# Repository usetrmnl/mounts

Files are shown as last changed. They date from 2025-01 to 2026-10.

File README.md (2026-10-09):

# TRMNL Mounts

this repo contains a growing collection of 3D printable models, useful for attaching TRMNL to magnetic surfaces like refrigerators or non stationary locations like a moving door.

to kickstart your own design, check out the `/resources` directory for component and enclosure STLs.

---

Mac 128k Display

designed by [@Jerrodh](https://makerworld.com/en/models/1516432-mac-128k-display-stand-for-trmnl-e-ink-dashboard#profileId-1588587)

---

### MainFrame

<kbd>TRMNL-MainFrame-Black</kbd>

designed by [Yogesh](https://makerworld.com/en/@mhatrey), [get the files](https://makerworld.com/en/models/1565549-mainframe-for-trmnl) or [watch the live demo](https://www.youtube.com/watch?v=4wjz7EKg_lw).

---

### anti-theft / public venue wall mount (OG)

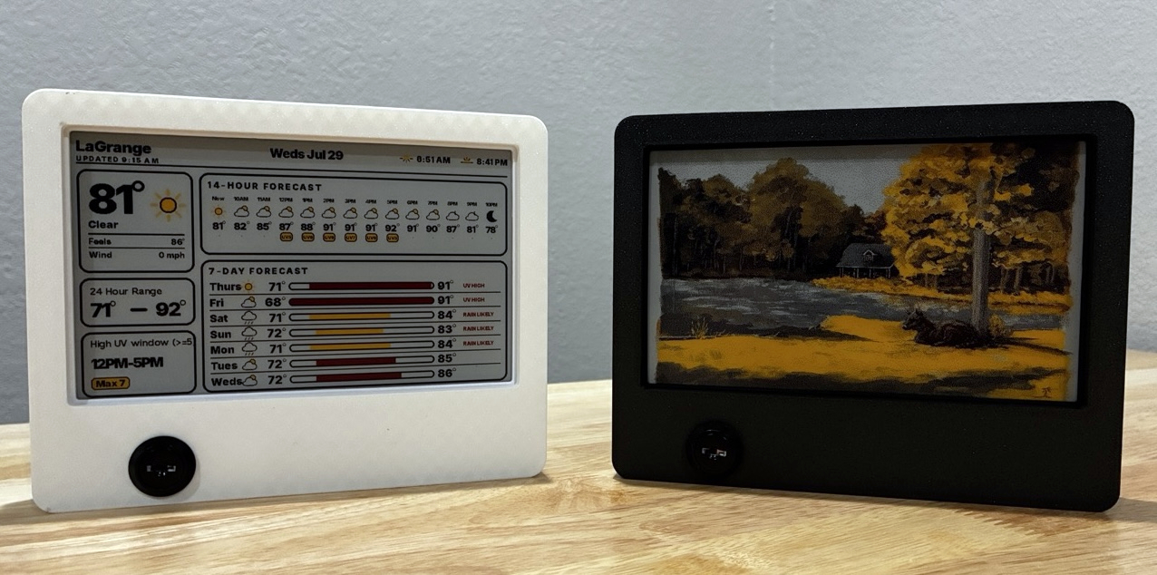
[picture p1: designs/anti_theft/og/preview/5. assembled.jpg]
anti-theft-og-preview


designed by TRMNL, [get the files](https://github.com/usetrmnl/mounts/tree/main/designs/anti_theft/og)

---

### X low profile mount

<kbd>x-low-profile-wall-mount</kbd>

designed by [@Bas](https://www.printables.com/model/1771188-trmnl-x-low-profile-mount), requires 4 (four) 10mm x 2mm magnets.

### hidden magnet

<kbd>minimal-magnet</kbd>

designed by [@jerieljan](https://x.com/jerieljan/status/1981025845100552695), **no 3D printer required**, just find/buy 30mm x 10mm x 3mm N42 NdFeB magnets.

---

### OG Faceplate Cover

<kbd>trmnl-og-faceplate-cover</kbd>

designed by [@maxelman](https://www.printables.com/model/1478341-trmnl-og-faceplate-cover)

---

### X Magnetic Fridge Mount

<kbd>trmnl-x-fridge-mount</kdb>

designed by [@t0nyz](https://makerworld.com/en/models/3391454-trmnl-x-magnetic-fridge-mount), requires 20mm x 10mm x 2 mm magnets.

---

### Multiboard TRMNL Mount

<kbd>multiboard-trmnl-mount</kdb>

designed by [@shahriar](https://makerworld.com/en/models/2436099-multiboard-trmnl-mount#profileId-2672745)

---

### Waveshare driver board

<kbd>!doctor-volt-cad</kbd>

requires [FreeCAD](https://www.freecad.org/), designed by [DoctorVolt](https://www.hackster.io/michalin70/build-your-own-ultra-low-power-e-ink-dashboard-3889ab) (file linked within).

---

### fridge magnet

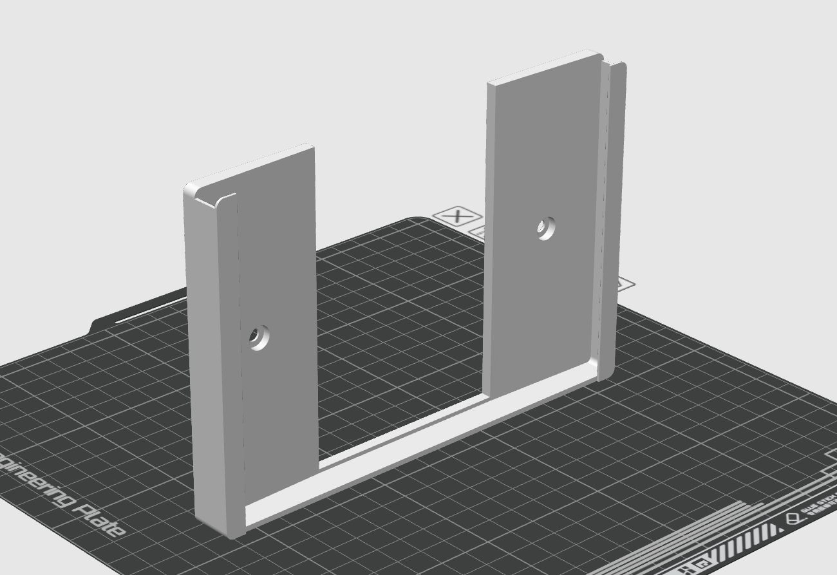
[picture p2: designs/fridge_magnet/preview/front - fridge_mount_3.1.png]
trmnl-fridge-magnet-front-preview
<kbd></kbd>

designed by TRMNL, [get the files](https://github.com/usetrmnl/mounts/tree/main/designs/fridge_magnet)

---

### OG mount for VESA arm system

<kbd>trmnl-vesa-mount</kbd>

requires VESA plate, designed by [az3dr](https://www.thingiverse.com/thing:7304914).

---

### sturdy fridge magnet

<kbd>trmnl-beefy-fridge-magnet</kbd>

designed by [@erikbuild](https://www.printables.com/model/1311911-trmnl-sturdy-fridge-magnet-mount)

---

### magnetic mounting plate

trmnl-magnetic-mounting-plate

designed by [@deisterhold](https://makerworld.com/en/models/1388620-trmnl-magnetic-mounting-plate#profileId-1438495)

---

### corner bracket

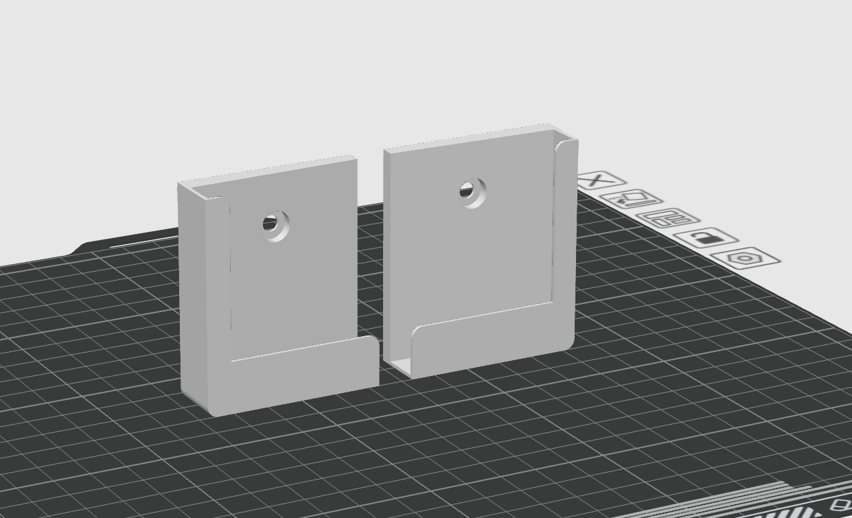
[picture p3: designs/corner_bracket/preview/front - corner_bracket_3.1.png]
corner-bracket-front-preview


designed by TRMNL, [get the files](https://github.com/usetrmnl/mounts/tree/main/designs/corner_bracket)

---

### Minimal Stand

trmnl-stand-ctrl-alt

designed by [@CtrlAlt](https://makerworld.com/en/models/1267576-trmnl-stand-for-e-ink-dashboard)

---

### BRKT

trmnl-brkt-jonschwenn

designed by [@jonschwenn](https://www.printables.com/model/1194757-trmnl-brkt)

---

### TRMNL Stand

trmnl-stand-rafbanaan

designed by [@rafbanaan](https://makerworld.com/en/models/1094514)

---

### TRMNL Command Strip

trmnl-command-strip-nail-hanger

designed by [@jgcaruso](https://makerworld.com/en/models/1189641-trmnl-command-strip-nail)

---

### [WIP] The H

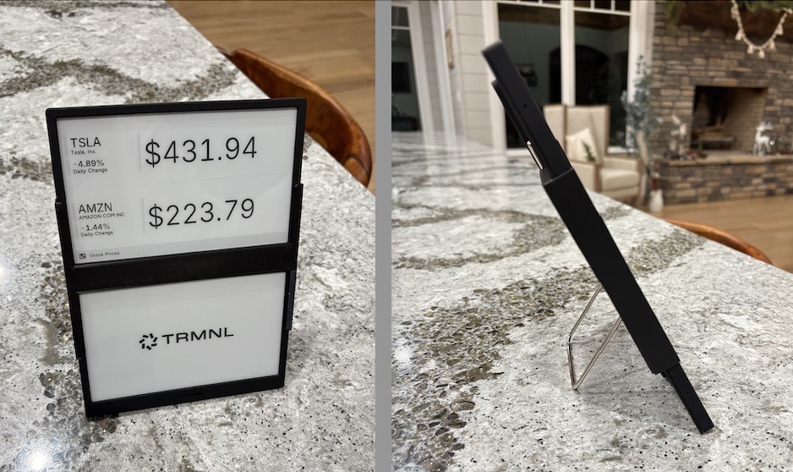
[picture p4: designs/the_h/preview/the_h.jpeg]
the-h-wip-preview


---

### SKÅDIS mount #1

trmnl-skadis

designed by [@coops on MakerWorld](https://makerworld.com/en/models/1156997-trmnl-skadis-mount)

---

### SKÅDIS mount #2

trmnl-skadis-2

designed by [@trakais on MakerWorld](https://makerworld.com/en/models/1469457-tmrnl-mini-hook-for-ikea-skadis-pegboard#profileId-1533577)

---

### Faceplate Cover

TRMNL-faceplate-cover

designed by [@Apolluna](https://www.printables.com/model/1313342-trmnl-faceplate-cover)

---

### TRMNL OG DIY Kit 10" Rack Mount

TRMNL-OG-DIY-Kit-10-Rack-Mount

designed by [@Lollo](https://www.printables.com/model/1575922-trmnl-og-diy-kit-10-rack-mount)

---

### Minimalist Mount for 19" Rack Blank Plate

TRMNL server rack mount

designed by [@erikbuild](https://www.printables.com/model/1316341-trmnl-minimalist-mount-for-19-rack-blank-plate)

---

### Wall Mount with button access and magnet+adhesive support

TRMNL button friendly wall mount

designed by [@curby](https://www.printables.com/model/1316584-trmnl-button-mount)

---

### Magnetic backplate

TRMNL-magnetic-backplate

designed by [@jareware_2647066](https://www.printables.com/model/1316234-trmnl-magnetic-backplate)

---

### Yet Another Magnetic TRMNL Mount

Magnetic TRMNL Mount

designed by [@sethangell](https://makerworld.com/en/models/1513288-magnetic-trmnl-mount#profileId-1584851)

---

### TRMNL BMP280

trmnl-bmp280-mount

designed by [@lanrat](https://github.com/lanrat/trmnl_plugins/blob/main/3D_models/Trmnl%20BMP280%20mount/README.md) for [DIY Environment Sensors](https://trmnl.com/blog/environment-sensors/)

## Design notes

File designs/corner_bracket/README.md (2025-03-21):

# TRMNL Mount - Corner Bracket

for placement on non-magnetic moving surfaces like doors, where the built-in recessed hook hole would be insufficient. also useful as a jig to arrange an array of devices on a wall with precisely butted edges.

### features

- 3x recessed spots on the back for magnet placement (5/8" diameter - ex [N35 Neodymium](https://www.magnet4sale.com/neodymium-magnet-n35-dia-5-8x1-16-disc-magnet-rare-earth-magnets/))
- 1x recessed screw hole for `#8` (Imperial) screw heads

### print instructions

DIY:

1. import STL file to any slicer tool (STEP file also provided for edits)
2. disable supports / not required
3. ~any infill should be fine

Online: we hear good things about Craft Cloud:
[https://craftcloud3d.com/upload](https://craftcloud3d.com/upload)

### installation

if using magnets, we recommend super glue with an extended curing time. your brand's bottle may require just 30-45 seconds, but in testing our magnets detached from the mount unless given at least 60 minutes to dry.

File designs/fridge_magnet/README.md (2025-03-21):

# TRMNL Mount - Fridge Magnet

for placement on magnetic surfaces, such as a kitchen fridge. may not work on smaller bar fridges or ice machines due to materials used in constructions.

### features

- easy removal from the mount for battery charging (entire mount can also be removed)
- recessed spots for up to 6x magnets (5/8" diameter - ex [N35 Neodymium](https://www.magnet4sale.com/neodymium-magnet-n35-dia-5-8x1-16-disc-magnet-rare-earth-magnets/))

in testing we found that only 3-4x magnets are required on flat surfaces. if a refrigerator door is curved, 6x magnets are recommended. if the magnetic surface is flat but some household members prefer to slam doors, 6x magnets are recommended.

### print instructions

DIY:

1. import STL file to any slicer tool (STEP file also provided for edits)
2. disable supports / not required
3. recommend 30% infill with rectilinear infill pattern

Online: we hear good things about Craft Cloud:
[https://craftcloud3d.com/upload](https://craftcloud3d.com/upload)

### installation

if using magnets, we recommend super glue with an extended curing time. your brand's bottle may require just 30-45 seconds, but in testing our magnets detached from the mount unless given at least 60 minutes to dry.

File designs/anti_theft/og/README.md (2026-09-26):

# TRMNL Mount - OG Anti-Theft (Public Venue)

anti-theft-og-preview

for public spaces with low supervision. incorporates a barrel lock and dovetail mechanism to prevent unauthorized removal.

### features

- 4x recessed screw holes on wall plate that fit most common fasteners
- works with generic 5/8" cam (barrel) locks (designed for [this model](https://www.amazon.com/dp/B0D72LGKTR))
- easy removal for ongoing charging and maintenance

### print instructions

DIY:

1. import STL file to any slicer tool (STEP file also provided for edits)
2. disable supports (not required)
3. ~any infill should be fine
4. PETG recommended but Basic PLA also works

Online: we hear good things about Craft Cloud:
[https://craftcloud3d.com/upload](https://craftcloud3d.com/upload)

### installation

see photos inside "preview" directory and follow along below:

1. attach back plate to a surface of your choice
2. put locking frame face down and insert OG device upside down (kickstand facing you)
3. slide cam lock into opposite side of locking frame, attach straight cam in vertical orientation
4. carefully attach locking frame to wall plate but aligning slots, then pushing locking frame downward
5. insert cam lock key and turn counter-clockwise to lock it against the wall plate's bottom hook

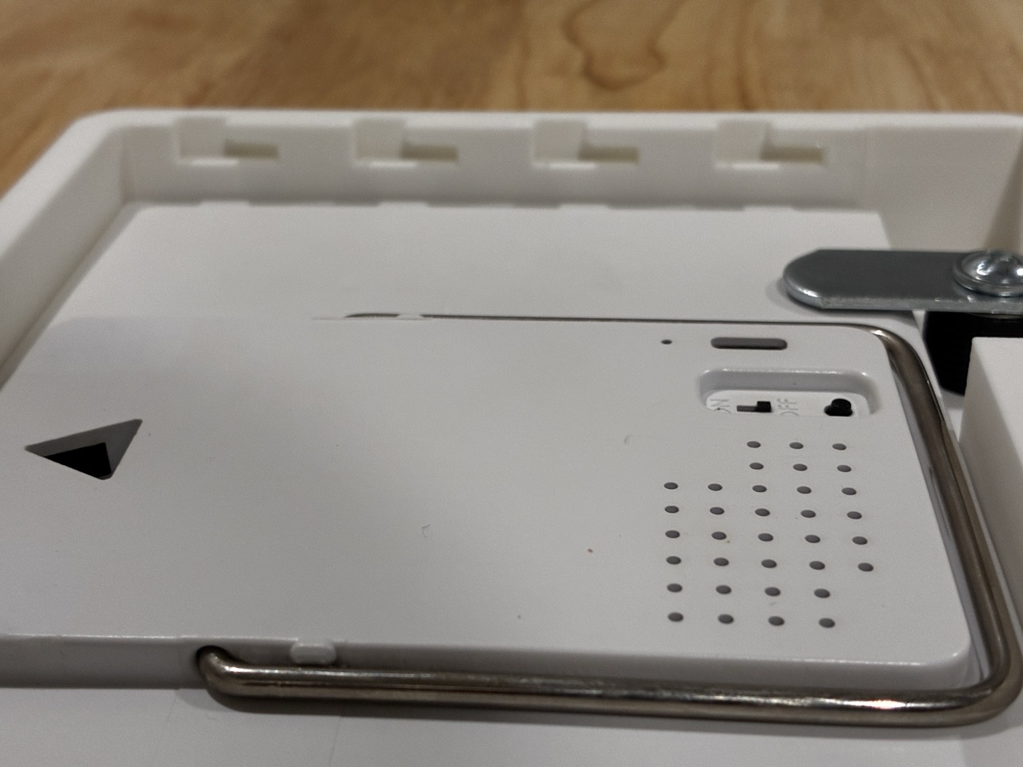
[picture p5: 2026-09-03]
designs/anti_theft/og/preview/3. wall plate slots.jpeg

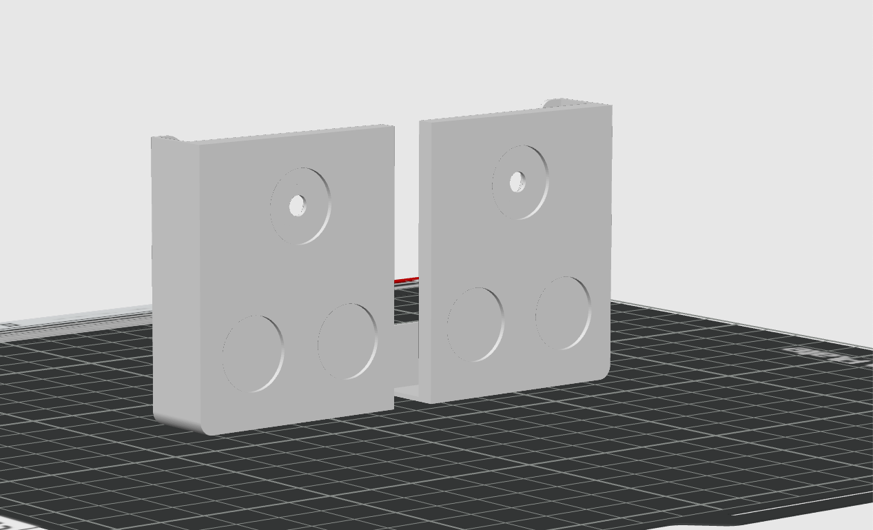
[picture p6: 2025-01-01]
designs/corner_bracket/preview/back - corner_bracket_3.1.png

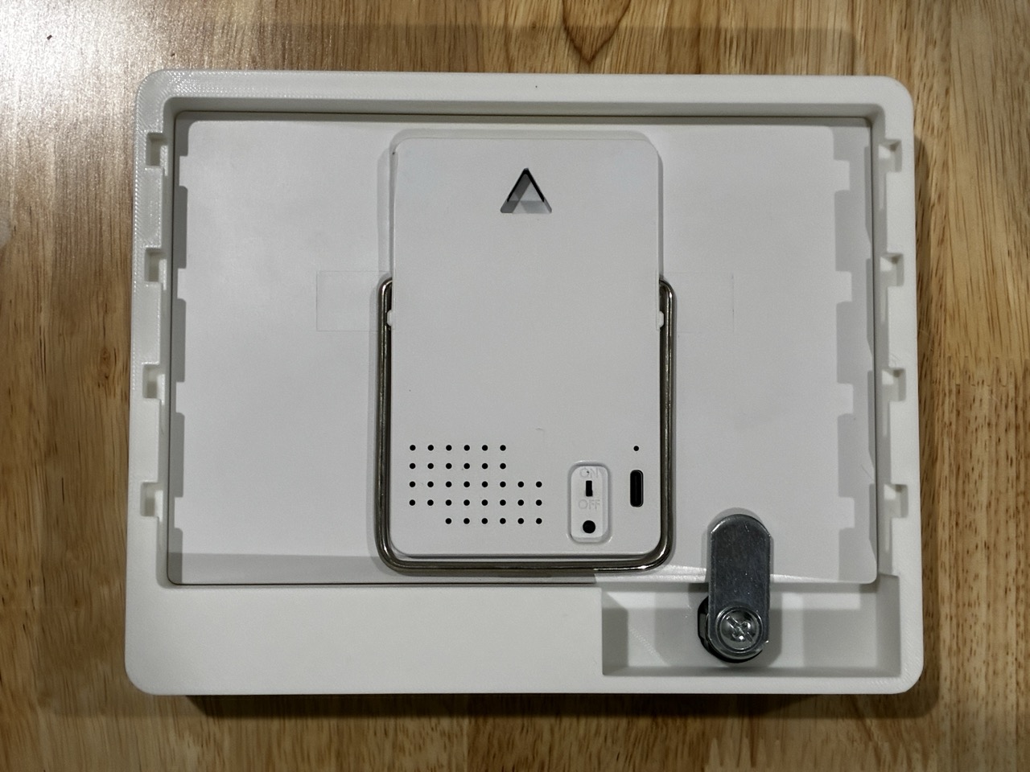
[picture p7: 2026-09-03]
designs/anti_theft/og/preview/2. device insertion.jpeg

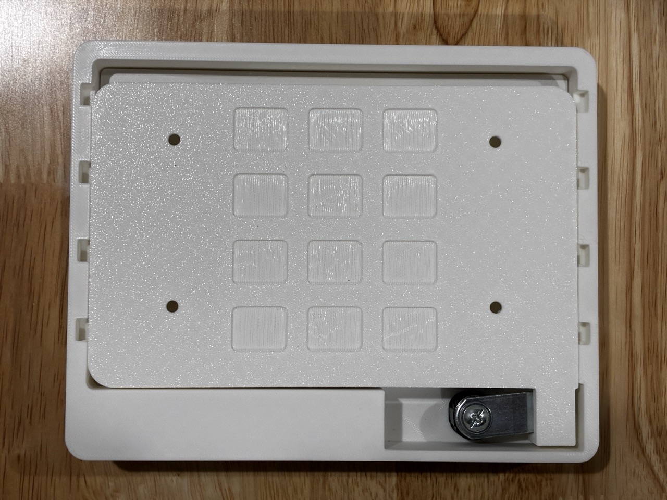
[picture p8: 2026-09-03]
designs/anti_theft/og/preview/4. cam lock.jpeg

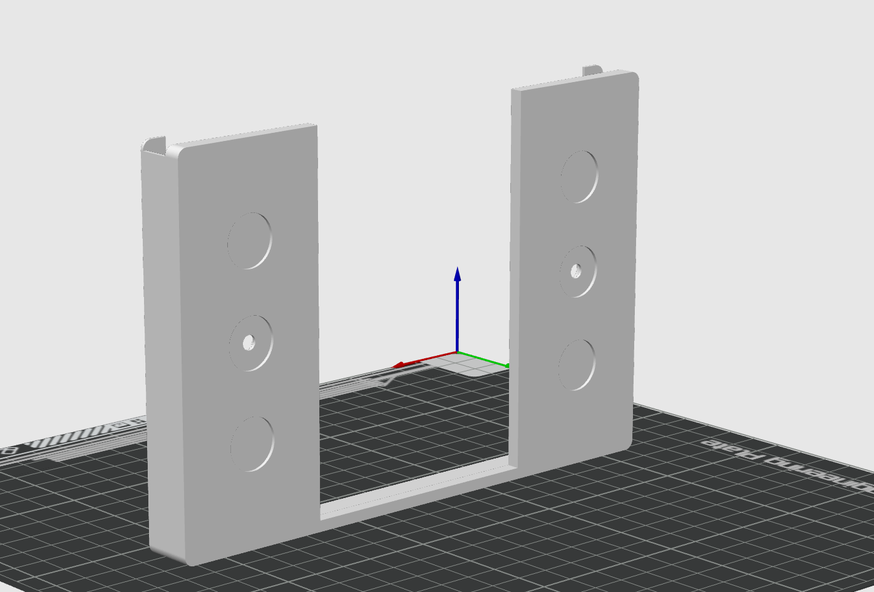
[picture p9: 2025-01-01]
designs/fridge_magnet/preview/back - fridge_mount_3.1.png

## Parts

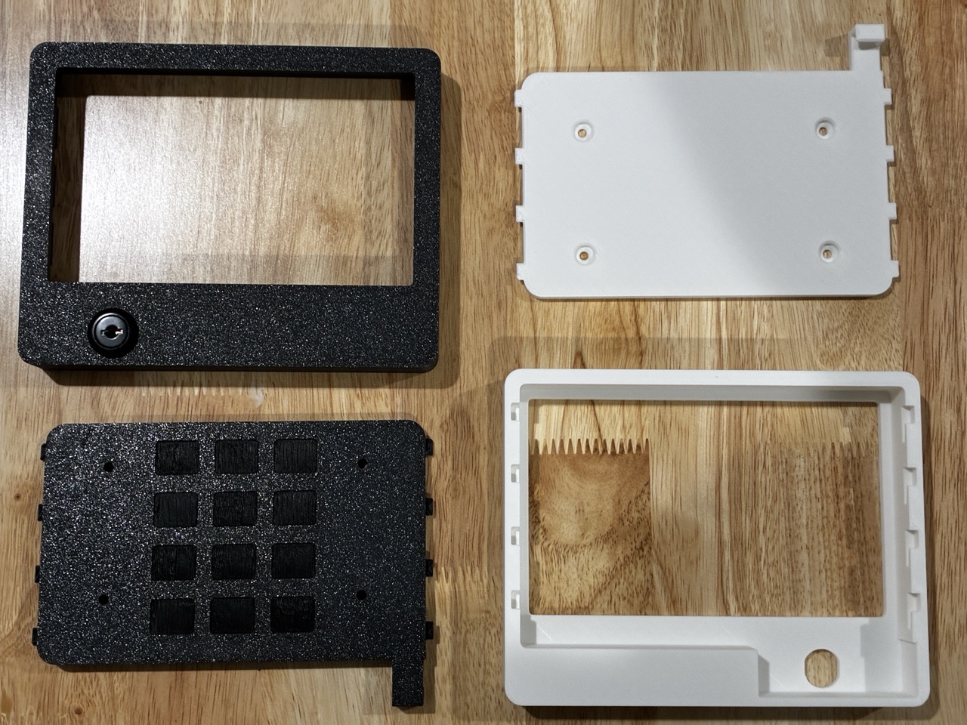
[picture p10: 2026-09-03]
designs/anti_theft/og/preview/1. individual components.jpeg

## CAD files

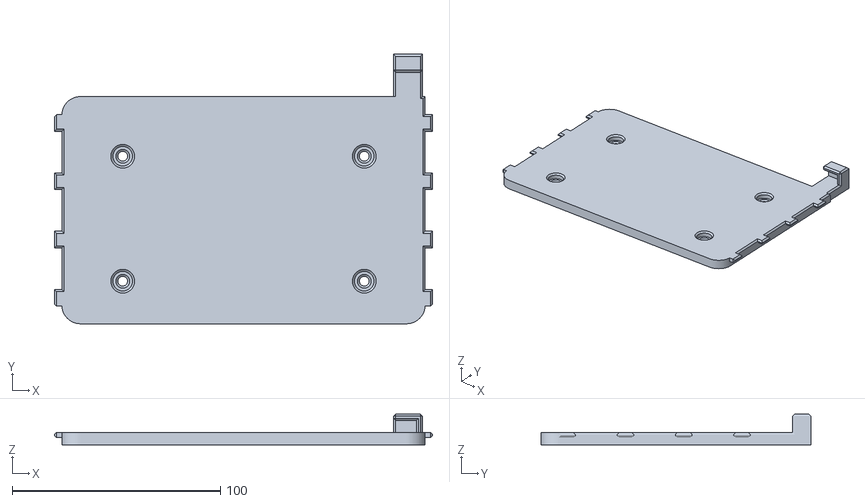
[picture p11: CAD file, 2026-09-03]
designs/anti_theft/og/wall_plate.stl
181.5 x 129.5 x 14.8

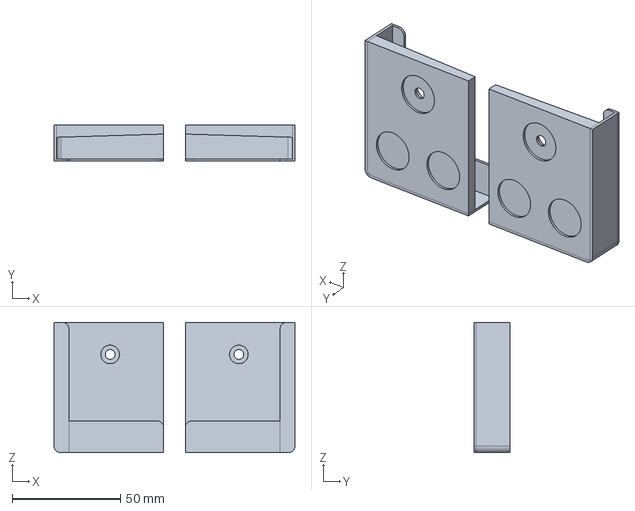
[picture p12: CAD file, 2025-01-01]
designs/corner_bracket/corner_bracket_3.1.stp
111.2 x 16.6 x 60.0 mm

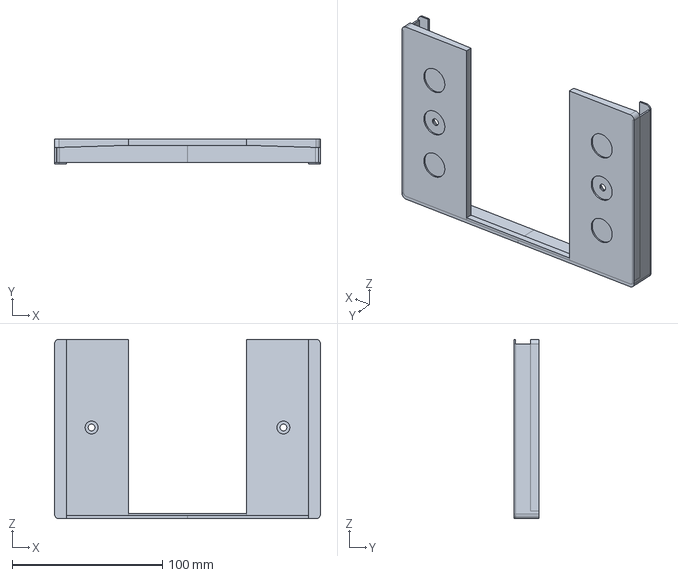
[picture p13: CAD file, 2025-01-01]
designs/fridge_magnet/fridge_mount_3.1.stp
177.2 x 16.6 x 119.5 mm

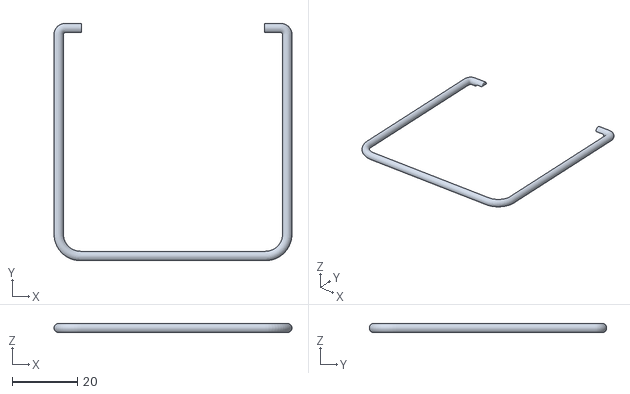
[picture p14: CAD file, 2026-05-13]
resources/og_model/KICKSTAND-2.4.stl
73.1 x 72.9 x 2.90

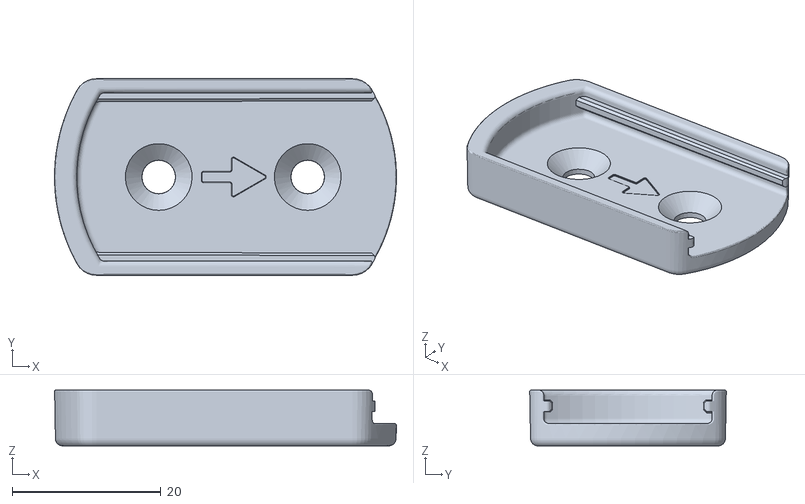
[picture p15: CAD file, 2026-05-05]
resources/x_model/U_MOUNT.stl
45.9 x 26.4 x 7.50

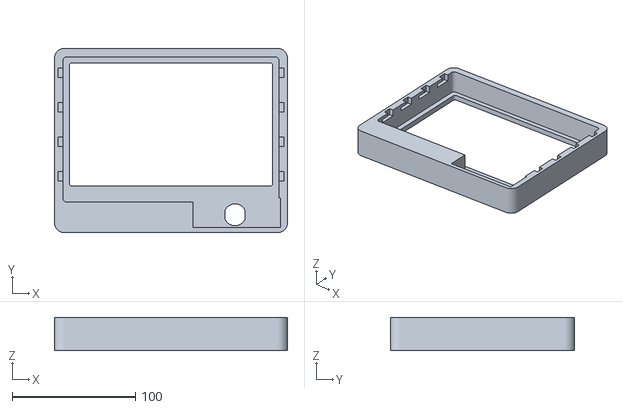
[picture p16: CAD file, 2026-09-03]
designs/anti_theft/og/locking_frame.stl
189.1 x 149.6 x 26.8

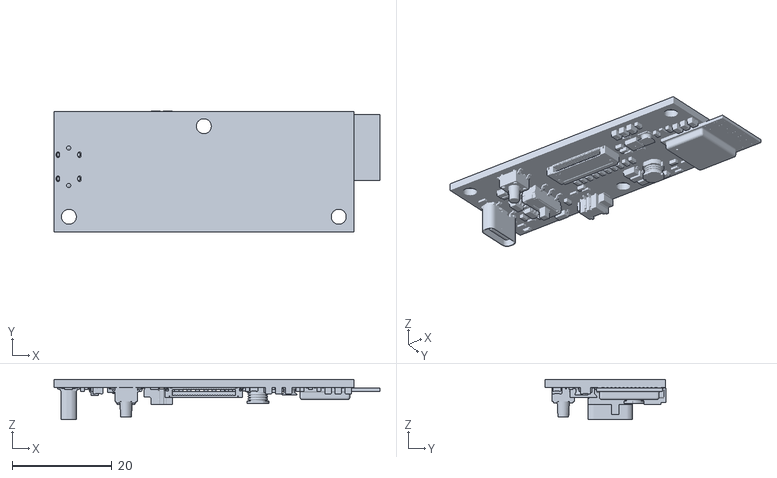
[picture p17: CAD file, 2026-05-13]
resources/og_model/PCBA.stl
65.2 x 24.2 x 8.10

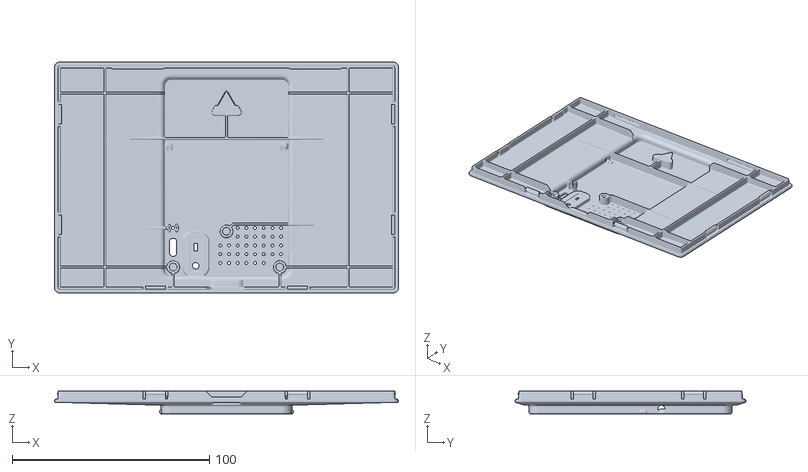
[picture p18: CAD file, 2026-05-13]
resources/og_model/ENCLOSURE_BACK-2.4.stl
174.3 x 116.9 x 11.6

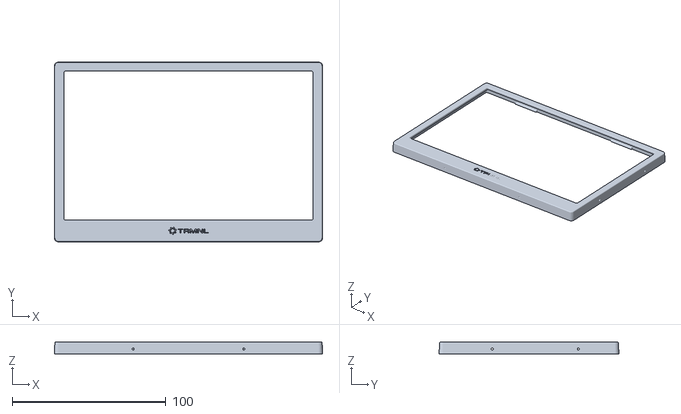
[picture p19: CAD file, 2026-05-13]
resources/og_model/ENCLOSURE_FRONT-2.4.stl
174.3 x 116.9 x 7.70

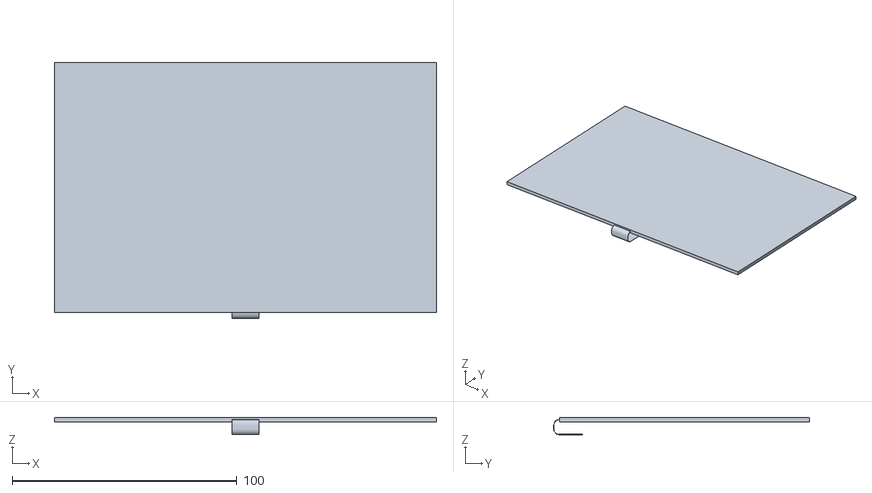
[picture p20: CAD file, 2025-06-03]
resources/og_model/EPD.stl
170.0 x 113.8 x 7.73

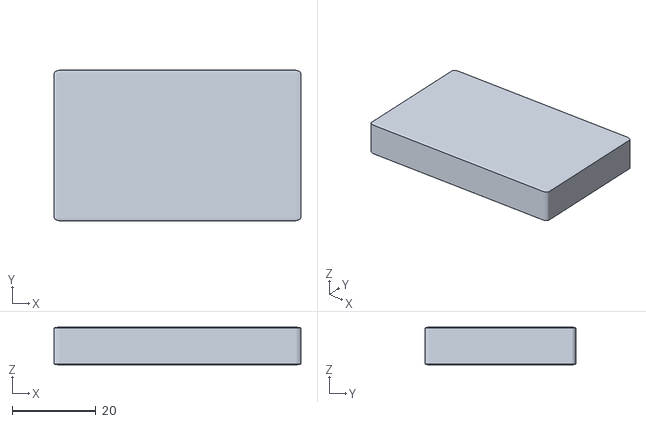
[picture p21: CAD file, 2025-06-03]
resources/og_model/BATTERY_LARGE.stl
59.0 x 36.0 x 9.00

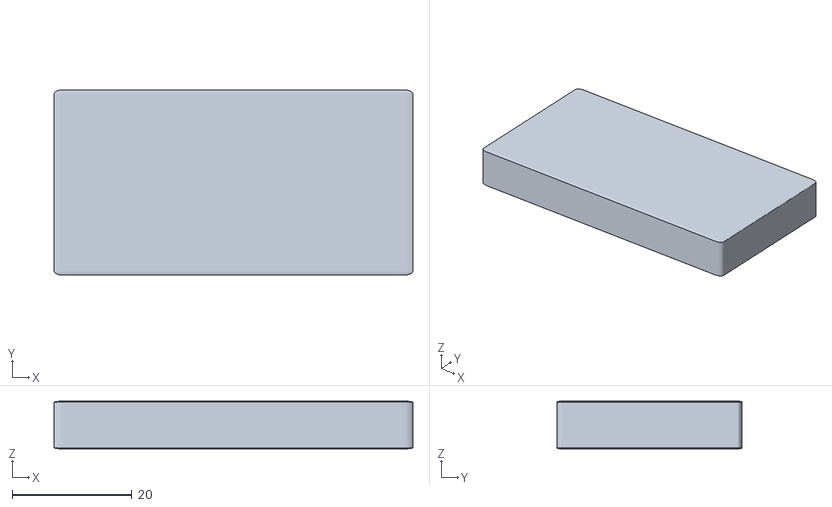
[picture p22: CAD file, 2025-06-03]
resources/og_model/BATTERY_STANDARD.stl
60.0 x 31.0 x 8.00

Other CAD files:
designs/corner_bracket/corner_bracket_3.1.stl
designs/fridge_magnet/fridge_mount_3.1.stl

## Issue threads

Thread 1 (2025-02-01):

Original Enclosure STEP Files?

hlipnick, 2025-02-01:
Excited to try out TRMNL.  Wondered if you'd be willing to release STEP files for the original enclosure parts.  Would be great to use a starting point for fully custom enclosures or integrating into other setups.  Thanks!

guillaumemolter, 2025-02-04:
Would love to get it too!

ryanckulp, 2025-02-09:
thanks for asking. at this time, we don't have plans to release the STEP files. but perhaps we can get a lighter weight STL edition available soon. will close this until that day comes.

hlipnick, 2025-02-11:
Thanks @ryanckulp   STL would be helpful, too.

ryanckulp, 2025-06-03:
@guillaumemolter @hlipnick hi folks, we just added some resources here. may include a basic case too if there is demand: https://github.com/usetrmnl/mounts/tree/main/resources/og_model

Closed 2025-02-09.

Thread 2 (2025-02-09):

cash bounty - water proof case

ryanckulp, 2025-02-09:
a customer intends to take TRMNL on their (internet-connected) boat and cycle through "weather forecasts, ambient conditions, and [boat] system details like battery voltage."

could be neat to build something like this, but with a tighter fit. not sure it's 3D print friendly, however.

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

open to suggestions and bids if someone wants to tackle.

Akisame-AI, 2025-02-09:
A friend of mine uses an android tablet and there are commercial tablet cases available that are waterproof. You could use one of those and put some foam in the back to secure it against shaking.

Shabik2000, 2025-02-11:
I am very comfortable with 3d software, got some experience in 3dprinting but I have not really done any weatherproofing device or product design etc. Having this said, I am an architect so we draw roof details etc and I am happy to spend a few hours to research but I can understand if you prefer to get someone having worked with similar devices etc. Let me know if you want me to have a stab.

hlipnick, 2025-02-13:
I'd love to take a crack at the bounty.  Will update back with early ideas

hlipnick, 2025-02-13:
@ryanckulp I'd like to take a crack at the bounty - worked up a starting plan so far.

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

ryanckulp, 2025-02-13:
sounds great @hlipnick !

ruohki, 2025-02-15:
Hear me out:

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

brynnb, 2025-02-15:
i'd agree on use of waterproof pouch, it's gonna be a lot less expensive, less bulky and less weight, and should be plenty waterproof. and as posted above, ones for ipad minis may fit the trmnl pretty well

Akisame-AI, 2025-02-15:
Why not a food vacuum sealing bag. Dirt cheap, perfectly waterproof and once every 3 months you cut it open, charge it and seal it back up again.
It also doesn't add bulk or weight.
I used that like 15-20 years ago during hiking to protect the emergency Mobile phone.
Alternatively, you can seal the bit around the charge port and put a rubber plug there so you don't need to rip open the bag every 3 months

hlipnick, 2025-02-15:
> > sounds great [@hlipnick](https://github.com/hlipnick) !
>
> I don't have the device yet (3 on the way - I'm trying to be patient!). Is there a page with accurate measurements? For now going to go by STL of the fridge mount.

Going to step away from this for now - I can't get too far past the thinking stage without accurate measurements of the device.  Excited to create and share some models once I've got mine!

ruohki, 2025-02-16:
I mean by providing offical 3d print files. People will think its save to use. I just think there is too much room for user error.

anmokhta, 2025-05-18:
Hello! I really want to take a crack at this, however FDM 3D printing (the most common type of 3D printing) has a limitation in that no matter what you do, solely 3D printing the case will not yield a truly waterproof case. This is a result of the layers not making a uniform surface that would be able to repell water. The most efficient way would be to print the case and then spay a water repellent coating that would get in between the layers and create the water proof uniform surface.

Could an acceptable solution involve an after printing process or does the solution need top be solely 3D printed with an added gasket?

I believe that SLA printing could potentially solve this issue as well as be able to make the case transparent enough to view the screen.

As an alternative I do know that there is a waterproofing electronics spray that FPV drone operators use to waterproof their drones. I understand that this would not qualify as a water proof case but could be a simpler solution.

yankobogdan, 2025-05-19:
@anmokhta
Spray wouldn't help considering the presence of a physical button, USB-C, pwr switch

Smth you can DIY and order from 3D print services makes more sense to me
Good point on FDM structure, but I think there should be a solution

My preference would be the screws and gaskets and no sprays if possible

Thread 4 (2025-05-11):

cash bounty - server rack mount

ryanckulp, 2025-05-11:
requested by a customer, we're happy to pay $200 for a minimal mount design that secures TRMNL to something like this:

https://www.amazon.com/Jingchengmei-Perforated-Mount-Blank-Panel/dp/B0CTKBQMLS

KodeSage, 2025-05-12:
@ryanckulp can I work on this?

ryanckulp, 2025-05-12:
@KodeSage if you have a TRMNL device, yes please.

KodeSage, 2025-05-12:
Oh alright I guess I will have to pass it to the next person.

ryanckulp, 2025-05-29:
thanks @erikbuild let's begin :)

erikbuild, 2025-05-30:
Adjustable placement prototype 1 on the printer... will report back Monday AM :)

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

erikbuild, 2025-06-02:
Initial release of mount.  Feedback welcome (@ryanckulp)! https://www.printables.com/model/1316341-trmnl-minimalist-mount-for-19-rack-blank-plate

ryanckulp, 2025-06-03:
nice one @erikbuild! thanks for making this. please email team@usetrmnl.com to claim the bounty ;)

will get this added to the repo README as well.

Closed 2025-06-03.

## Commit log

2025-01-01 Fridge Magnet infill/pattern reco
2025-01-01 corner bracket - on glue curing time
2025-01-01 fridge magnet - on glue curing time
2025-03-13 Added coops skadis mount
2025-03-21 suggest Craft Cloud as a print farm
2025-03-21 fridge mount - Craft Cloud
2025-03-21 craft cloud - Corner bracket
2025-05-06 magnetic mounting plate by @deisterhold
2025-05-29 sturdy fridge magnet by @erikbuild
2025-05-30 Add SKÅDIS mount
2025-06-03 minimalist server rack mounting plate by @erikbuild
2025-06-03 button-friendly wall mount by @curby
2025-06-03 OG TRMNL 3D models for design kickstart
    [EPD_TRMNL_OG.stl, LARGE_BAT_TRMNL_OG.stl, STANDARD_BAT_TRMNL_OG.stl]
2025-06-09 magnetic backplate by @jareware_2647066
2025-06-14 magnetic TRMNL mount by @sethangell
2025-10-26 hidden magnet (no 3D printer required) by @jerieljan
2026-01-12 Waveshare driver board design by Doctor Volt
    Added section for Waveshare driver board with requirements and design credits.
2026-01-30 add TRMNL OG DIY Kit 10" Rack Mount by Lollo
2026-02-23 Multiboard TRMNL Mount by @shahriar
2026-03-05 Add VESA mount by az3dr
2026-04-03 BMP280 mount by @lanrat
2026-05-05 begin X OSS-ing - u_mount
    [U_MOUNT.stl]
2026-05-13 WCGW OSS OG
    [BATTERY_LARGE.stl, BATTERY_STANDARD.stl, ENCLOSURE_BACK-2.4.stl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]
2026-07-05 Add X low profile mount by @bas
2026-09-03 OG - anti theft mount
2026-09-03 OG anti theft STLs
    [locking_frame.stl, wall_plate.stl]
2026-10-04 Add X Magnetic Fridge Mount by @t0nyz
    Added section for X Magnetic Fridge Mount with details and image. Source: https://www.reddit.com/r/trmnl/comments/1wx4f4d/trmnl_x_magnet_strength_wasnt_strong_enough_for/
2026-10-09 Fix link for anti-theft wall mount files
    Updated link to the anti-theft wall mount files.
